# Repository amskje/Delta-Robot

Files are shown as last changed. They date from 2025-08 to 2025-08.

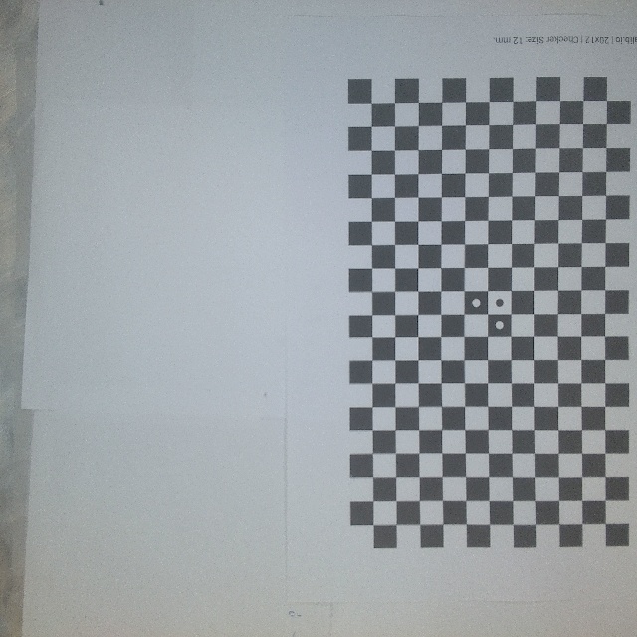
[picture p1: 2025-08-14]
Calibration/Camera_calibration/calibration_images/chessboard_frame17.jpg

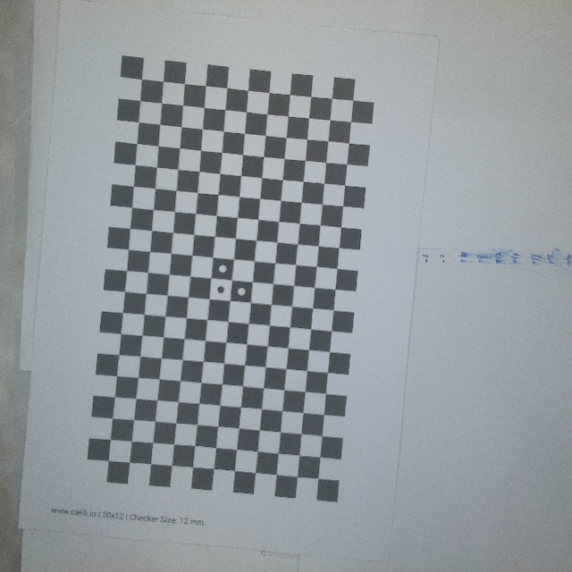
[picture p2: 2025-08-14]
Calibration/Camera_calibration/calibration_images/chessboard_frame7.jpg

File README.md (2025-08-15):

Manual for Delta-Robot @ NOV 2025
# Contents
[Abstract	1](#_toc724300322)

[Starting the system	1](#_toc895251242)

[Hardware overview	1](#_toc675706389)

[Jetson	2](#_toc1815479896)

[Raspberry Pi	2](#_toc84646506)

[Arduino	2](#_toc1544824068)

[Software nodes	2](#_toc146301729)

[Jetson	2](#_toc1467893155)

[Arduino	5](#_toc1835169055)

[Raspberry Pi	5](#_toc1901772002)

[Calibration	5](#_toc850224337)

[YOLOv8	6](#_toc1308711842)

[General	6](#_toc500146127)

## Abstract
This project is a Delta-Robot designed to sort and pick Twist candy.

The robot is supposed to follow this workflow:

1. Read user input through the HMI
1. Identify Twist matching the request
1. Pick up, transport, then deliver

The robot also has a manual mode, which lets you move it in the X, Y, and Z directions and control the pump on or off. 
## Starting the system
To start the system, just press the power button and wait. The PI boots to desktop and then starts the GUI. It takes some time to start the GUI, so be patient. When the HMI shows two options, “Manuell” and “Automatisk”, and the motor has moved to home position over the drop off location, the system is ready.

## Hardware overview
To summarize how the robot works we will walk through most of the electronics and wiring.

The delta robot has three stepper motors with a 10:1 gear ratio, each controlled by its own motor driver. These motors move the forearms and biceps, which control a suction cup end effector. The suction is generated by a vacuum pump located at the bottom of the robot. The pump is controlled by the Arduino through a relay, and the Arduino is also connected to a vacuum sensor that measures the pressure in the suction line.

A Jetson is mounted on top of the robot. It acts as the main controller, communicating with both the Arduino and the Raspberry Pi. The entire system is powered by a single power supply. Two DC-to-DC converters are used: one provides 5V for the Arduino, and the other provides 12V for the Jetson, lights, and vacuum pump. The motor drivers are powered directly from the 36V output of the main power supply.

On the top center metal plate, a Raspberry Pi camera is mounted for the robot’s vision system. At the bottom, there is a Raspberry Pi touchscreen mounted on a sliding rail, which can be pulled out to select a candy.

Most of the electronics are located at the bottom of the robot and are covered with plexiglass. To access parts like the Arduino, you’ll need an H3 Bahco screwdriver. The pickup area (the white 3D-printed plate) is screwed and glued to the metal plate. The sliding rail is also glued to the metal plate. The black plexiglass side, which has the power connection, is attached with a bracket, and the bracket is glued in place. 
### Jetson
The most powerful computer we have. Connected to the camera and runs both the YOLO model and the calculations related to kinematics. Jetson communicates with the RPi though a ethernet cable using ROS 2 and uses serial communication to communicate with the Arduino. 
### Raspberry Pi
Has a touchscreen directly connected to it. Acts as the HMI and is quite dumb.
### Arduino
Is essentially the motor controller. Tells the motor drivers how many steps to move, and in what direction. Also acts as the interface between software and analogue signals. E.g. triggering a limit switch or monitoring the air pressure in the hose.
## Software nodes
Here is link to the repository: <https://github.com/amskje/Delta-Robot>. All used code *should* be here. The repository contains all the code for the different nodes. It also includes a “Datasheets” folder with datasheets for all the robot’s components, and a folder with the 3D models that were designed and printed during the project. 
### Jetson
General information

Currently it is running Linux with Ubuntu 20.04 OS. Here is a summary of some information which could be helpful:

IP address: 192.168.1.20/24

ROS version: Foxy (i.e. 2)

Username: jetson@yahboom

Password: yahboom

(More information can be found in the config file).

There is also some trickery with switching between using its ethernet port for ROS or regular internet. In order to prep for internet just type the following in a terminal of your choice: “nmcli connection up internet-eth”. If you need ROS, this is the command: “nmcli connection up ros-direct”.

The repository is located at ~/Documents/code/Delta-Robot/. 

Boot:

The main.py program runs on boot via the /etc/systemd/system/ros2\_boot.service file and the /Documents/code/Delta-Robot/Jetson/startup\_launcher.sh file. The starup\_launcher script prepares the environment and runs the main.py. And the ros2\_boot.service tells how and when to automatically launch the main.py. 

Remember to check or set the ros-direct network connection profile when setting the Jetson to run the main.py on boot, to make sure the communication over ros is working. To activate the ros-direct connection to be automatically set, run: “nmcli connection modify ros-direct connection.autoconnect yes”, and to check if the connection is set automatic: “nmcli connection show ros-direct". 

To start the automatic boot, run this in the terminal:

`        	`sudo systemctl daemon-reexec

`        	`sudo systemctl daemon-reload

`        	`sudo systemctl enable ros2\_boot.service

sudo systemctl start ros2\_boot.service

To see the status of the program:

sudo systemctl status ros2\_boot.service

To stop the automatic booting program:

sudo systemctl stop ros2\_boot.service

To restart the program:

sudo systemctl restart ros2\_boot.service

To disabling the automatic boot of the program:

sudo systemctl disable ros2\_boot.service

If the automatic boot is enabled and you connect the Jetson to display, mouse and keyboard, the program will still run in the background. If the program is stopped, you can run the restart line to start it again, if the program is disabled you can run the four start automatic boot lines to make it run on boot again. To see the live output from the program while its running in the background you can run this:

journalctl -u ros2\_boot.service -f

To only see a set number of the last output lines run:

journalctl -u ros2\_boot.service -n 30 --no-pager

NB: need to comment out cv2.imshow in the code when running the program on boot

Code:

The main.py script controls the main program and uses different functions from files inside the modules folder. The modules folder also include the AI model weightsV3.pt, which is used to detect Twist. 

The module files are:

- vision.py
- control.py
- kinematics.py
- comms.py
- weightsV3.pt

The vision.py file is responsible for running inference on the video stream. It contains a function called start\_inference\_thread, which starts a background thread that continuously analyzes the video frames while the program is running. The goal is to detect different Twist types. The detection happens in a function called detect\_target, which returns a list of detected twists. Each item in the list is a tuple containing the name of the twist, its position in millimeters (x\_mm and y\_mm), and the confidence of the detection. For some Twist types, the function also fine-tunes the center position to make sure it’s as accurate as possible.

The control.py file handles the delivery part of the robot system. It takes care of moving the robot to pick up the Twist from a given location and then move it to the drop-off point. This file sends the proper commands to the Arduino to make that happen. It also has logic to deal with situations where a movement needs to be stopped halfway, like if an abort is triggered. In addition, it includes helper functions such as go\_to\_pos, which moves the robot to a given position, and retreat\_home, which brings it back to its starting or resting position.

The kinematics.py file does all the calculations needed to figure out how the robot should move. It takes cartesian positions (like where the Twist is and where it should go) and turns them into motor step values that the Arduino can use to move the robot arms correctly.

The comms.py file sets up and manages communication between the Jetson, Raspberry Pi and the Arduino. The Jetson uses ROS to talk to the Raspberry Pi and serial communication to talk to the Arduino. This file includes functions to send and receive messages, and it also has a function called wait\_for\_ack that waits for a specific response from the Arduino after sending it a command. 
### Arduino
The repository is located at home/delta/Desktop/Delta-Robot/Arduino.

The Arduino side consist of one file: Arduino\_main.ino. This script executes the instructions sent from the Jetson.

### Raspberry Pi
The repository is located at home/delta/Desktop/Delta-Robot.

IP addres: 192.168.1.10/24

The GUI is run in a docker to be able to use ROS. The docker is named: delta-robot-app and the container is named delta\_gui. When the system starts and the Pi boots to Desktop, the executable /home/delta/.config/autostart/HMI.desktop (HMI\_Docker) is run automatically. This script starts /home/delta/start-delta-gui.sh. This script starts the same container every time, and the main file: /home/delta/Desktop/Delta-Robot/RaspberryPi/GUIMultiplePages.py

To pull new code, do the following inside the home/delta/Desktop/Delta-Robot folder:

- Docker stop delta\_gui
- Docker rm delta\_gui
- Git pull
- Cd RaspberryPi
- Docker build –t delta-robot-app .
- Reboot

If you want to connect the RPi to Wi-Fi you need to pull out the ethernet cable to get an internet connection. 

NB: There is a known bug with the manual screen that we haven’t had time to solve. When the system first boots, the manual screen doesn’t work properly. However, if you exit to the start screen and then return to the manual screen, it works as expected. We suspect this is due to a communication issue, it seems that the “MANUAL” message from the Raspberry Pi to the Jetson is not being received correctly at the first time, so the Jetson’s main.py does not switch to the “manual” state.
### Calibration
The robot is calibrated using three methods:

1: The camera is a bit non-linear along the edges. This is accounted for by “undistorting” the picture. The undistorting function uses the file camer\_calibration.npz. This is made by taking some pictures of a chessboard in different locations around the workingarea. To produce a new calibration, the file /Delta-Robot/Calibration/Camera\_calibration/Calibrate\_camera.py can be used. When running this script, you have to define the size of the chess squares. Capture\_image.py can be used to take the pictures. 

2: When the camera returns the x and y positions of the target, these values needs to be mapped to the real world coordination system. This is done by calculating a Homography matrix. The current matrix is stored in the file: homography\_camera.npy. To recalculate this matrix, the script /Delta-Robot/Calibration/Camera\_calibration/Compute\_homography.py can be used. This requires a picture of a chessboard where the center is located exactly at the origin of the “world” coordinate system, as well as the axes aligned.

3: Different parts of the robot might be a little “off”, so a Homography matrix is calculated to map the robots coordinates to the “world” coordinates. The matrix is stored in the file homography\_ROBOT\_WORLD.json. A new matrix can be calculated by using the script /Delta-Robot/Calibration/robot\_world\_calibration.py. This requires that you run the robot to different coordinates and measures the actual “world” position of that order. You can use the script /Delta-Robot/Jetson/manualControlWithVideoInference.py to move the robot to desired locations. 

When calibrating it is important that the reference coordinate system in step 2 and 3 are exactly the same.

The coordinate system of the robot has its x axis pointing away from the HMI screen, the y axis pointing to the right and the z axis pointing up towards the roof.

## YOLOv8
In case there is need for training a new model, there is a bit over a thousand images that are stored in the private cloud belonging to Amund. These images also have corresponding .txt files with bounding boxes for training and validation of YOLO models. Note that the .txt files are in YOLO format, but it is probably easy to convert to some other format.

We recommend using *LabelImg* for manual labeling.

The current model is referred to as “weightsV3.pt” on github. You can find it at /Delta-Robot/Jetson/modules/weightsV3.pt. It is based upon the pre-trained nano model from Ultralytics. It ran 40 epochs on the dataset with some various augmentations.

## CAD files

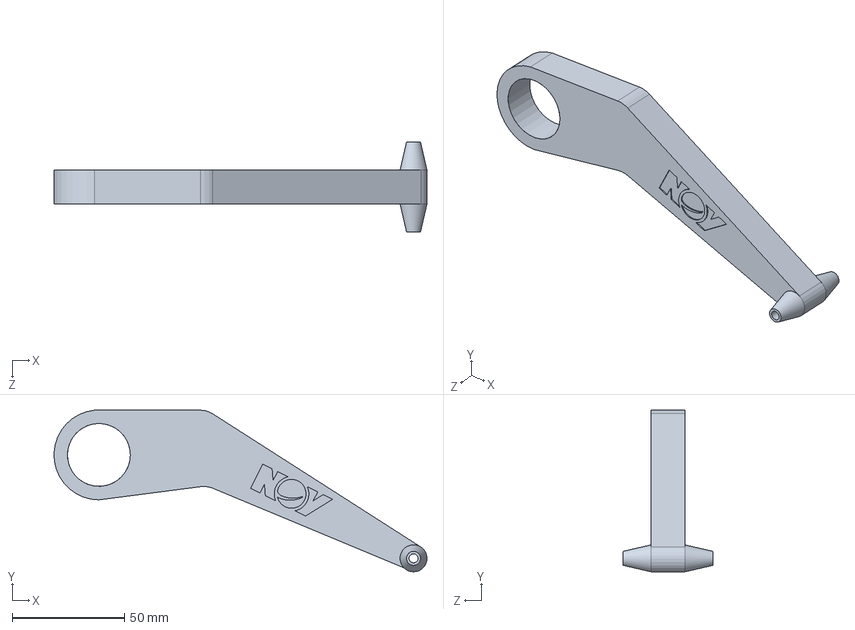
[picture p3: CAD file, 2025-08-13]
3D models/Heimelaga deler (.stl)/Bicep/BicepV3.SLDPRT
166.0 x 71.9 x 40.0 mm

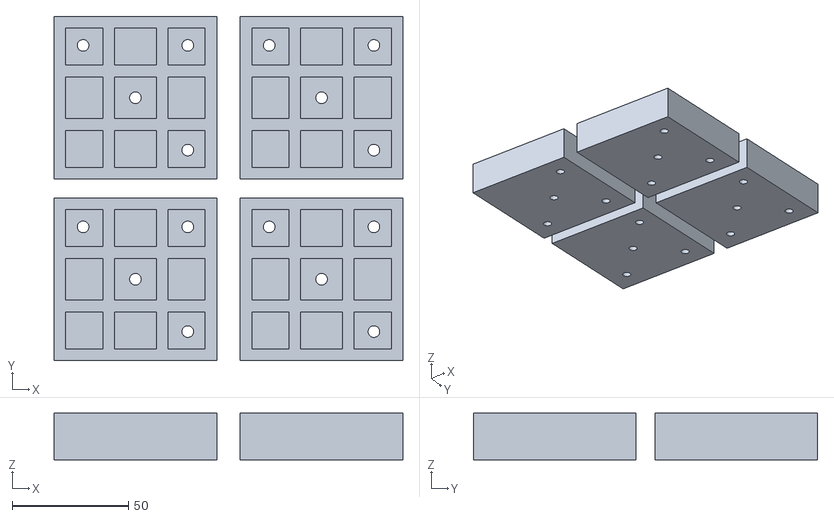
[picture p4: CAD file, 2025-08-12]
3D models/Heimelaga deler (.stl)/Bordbein/BordbeinV1 4stk.stl
150.0 x 148.0 x 20.0

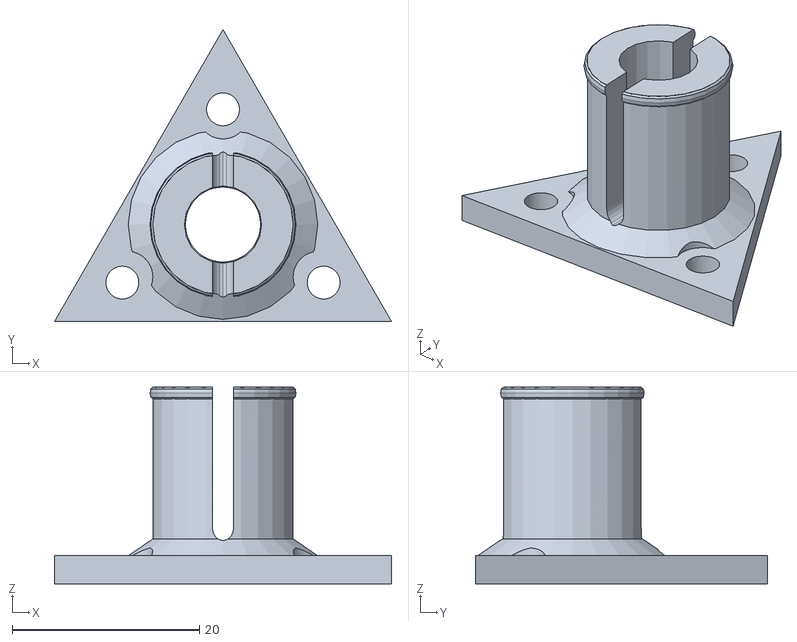
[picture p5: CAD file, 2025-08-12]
3D models/Heimelaga deler (.stl)/Endeffektor/Endeffektor V1.stl
36.0 x 31.2 x 21.0

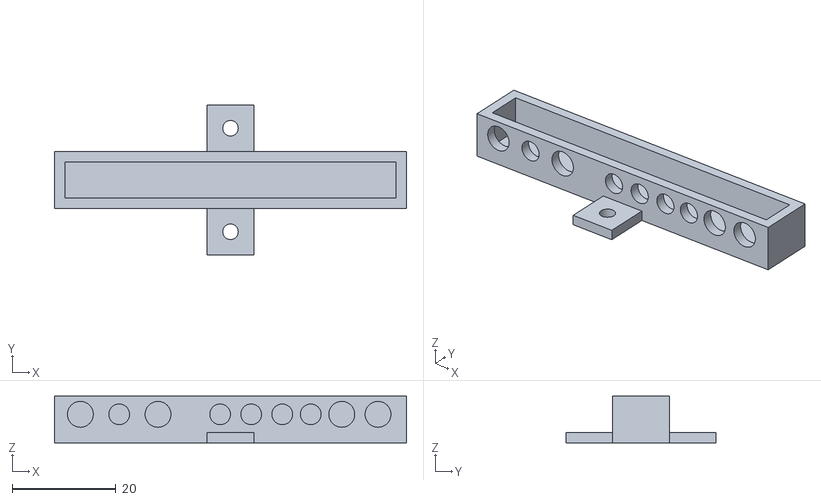
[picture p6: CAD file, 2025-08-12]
3D models/Heimelaga deler (.stl)/GND Rail/GND RailV1.stl
68.0 x 29.0 x 9.00

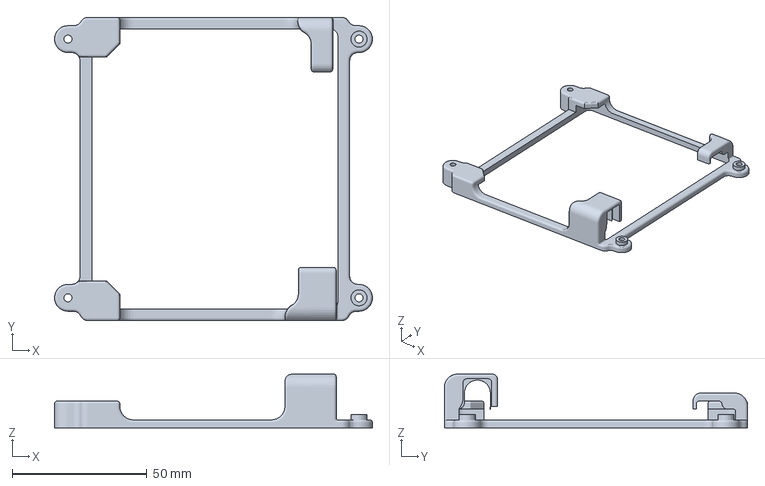
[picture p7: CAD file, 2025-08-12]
3D models/Heimelaga deler (.stl)/Jetson casing/C3-JetsonXavierNX-Mount.3mf
118.0 x 112.6 x 20.0 mm

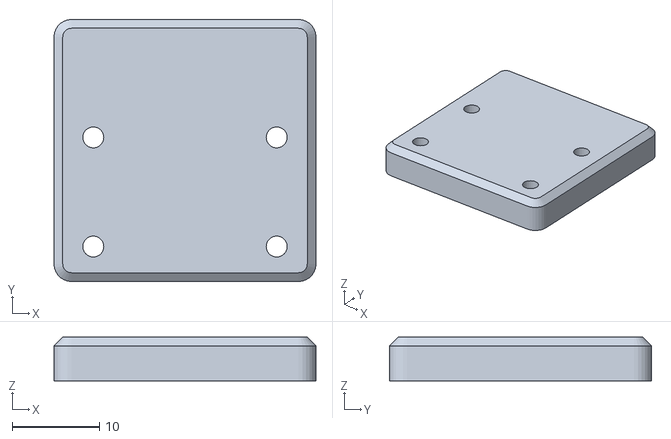
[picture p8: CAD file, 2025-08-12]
3D models/Heimelaga deler (.stl)/Kamera casing/Kamera casing del 1 V1.STL
30.0 x 30.0 x 5.00

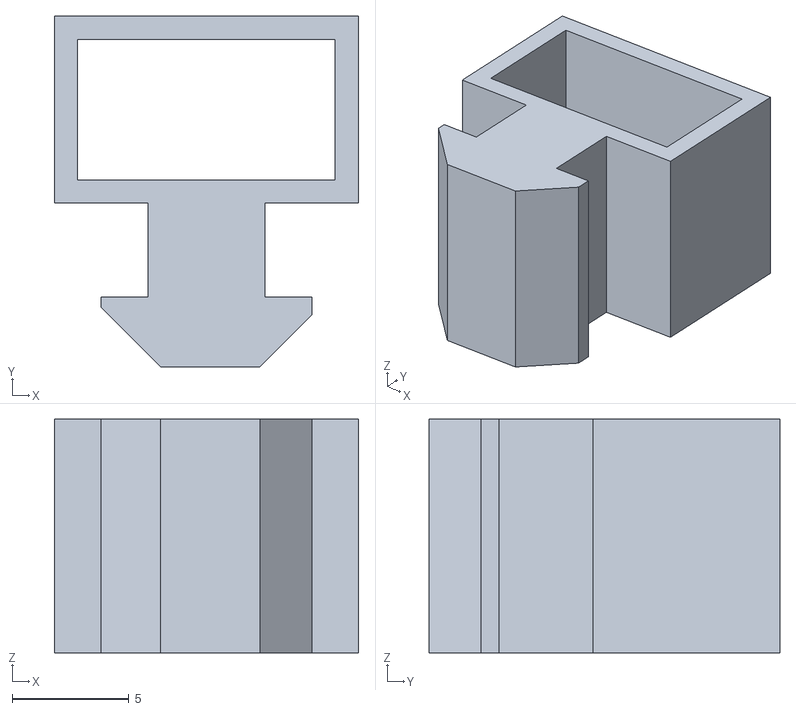
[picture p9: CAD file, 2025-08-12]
3D models/Heimelaga deler (.stl)/LED knagg/LED knagg V3.stl
13.0 x 15.0 x 10.0

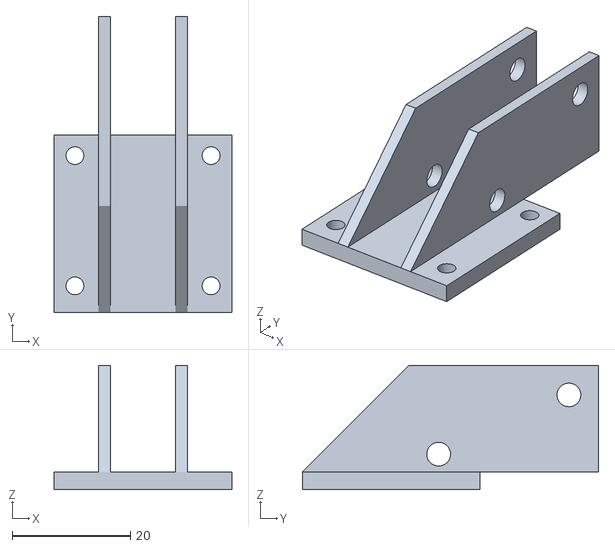
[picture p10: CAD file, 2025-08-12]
3D models/Heimelaga deler (.stl)/Limiter bracket/Limiter bracketV2.stl
30.0 x 50.0 x 21.0

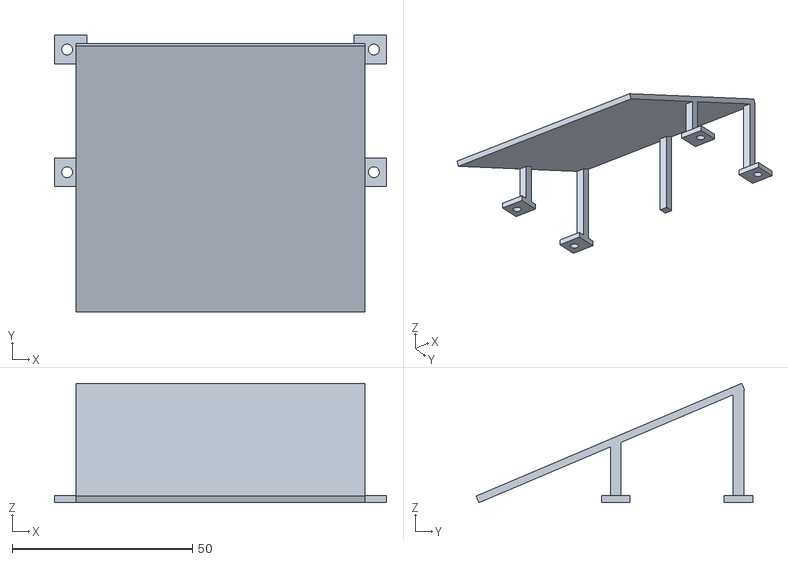
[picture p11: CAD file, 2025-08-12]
3D models/Heimelaga deler (.stl)/Sklie/Twistsklie.stl
92.0 x 76.7 x 33.1

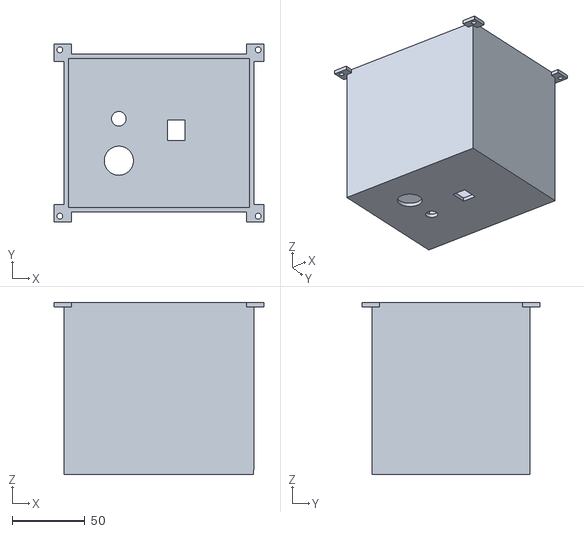
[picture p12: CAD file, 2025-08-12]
3D models/Heimelaga deler (.stl)/Støydemping/PumpecasingV1.stl
144.0 x 122.0 x 118.0

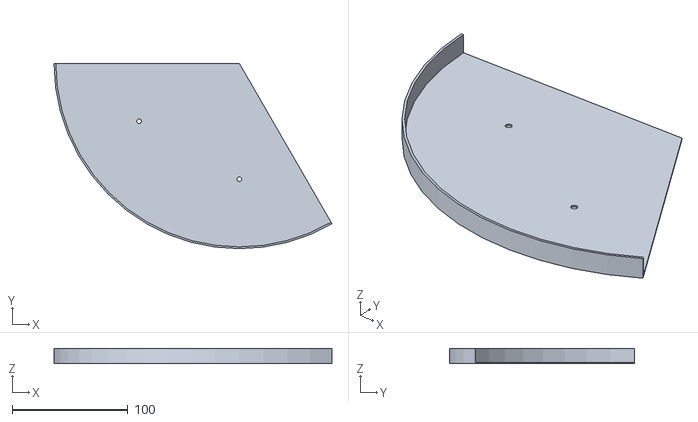
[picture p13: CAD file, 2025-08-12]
3D models/Heimelaga deler (.stl)/Underlag/UnderlagV2.stl
240.0 x 160.0 x 13.0

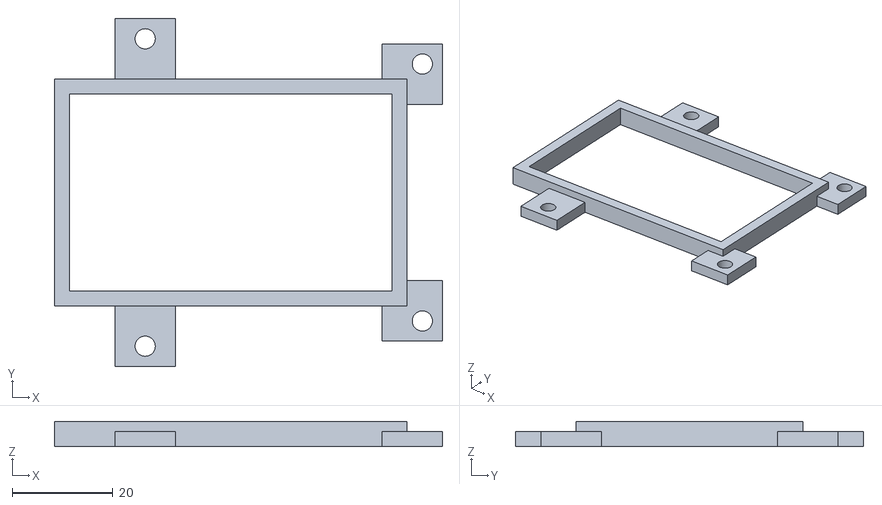
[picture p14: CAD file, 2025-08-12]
3D models/Heimelaga deler (.stl)/Vakuumpumpe casing/Vakuumpumpe casing (berre skål)V2.stl
77.0 x 69.0 x 5.00

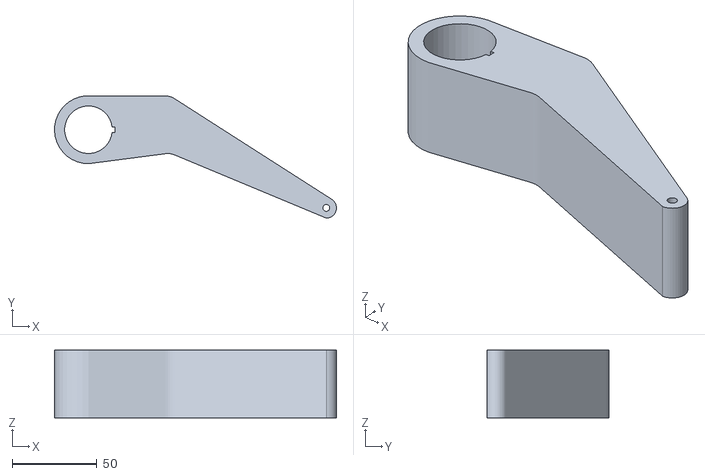
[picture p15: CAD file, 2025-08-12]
3D models/Heimelaga deler (.stl)/Bicep/Bicep40mmV2.STL
166.0 x 71.9 x 40.0

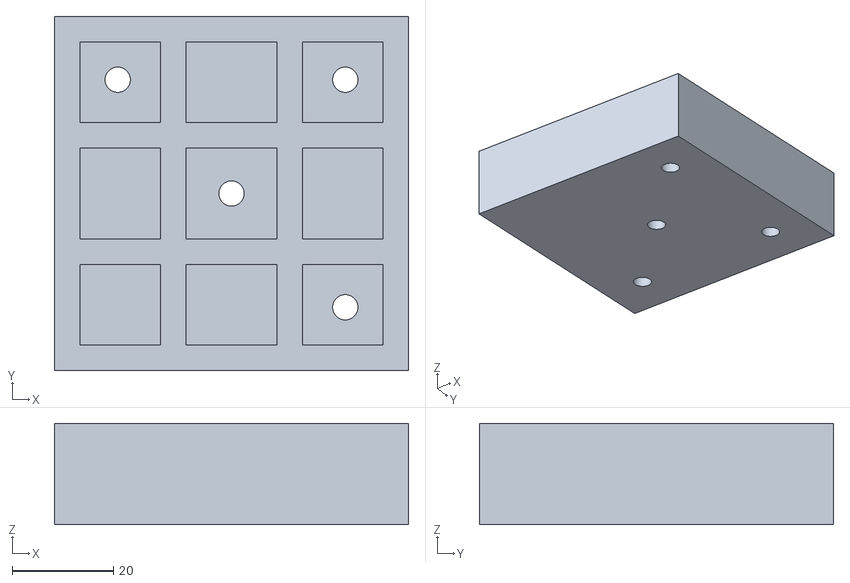
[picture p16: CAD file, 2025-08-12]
3D models/Heimelaga deler (.stl)/Bordbein/BordbeinV1 1stk.stl
70.0 x 70.0 x 20.0

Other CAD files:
3D models/Prosjekt (.3mf)/Bordbein/BordbeinV1 4stk.3mf
3D models/Heimelaga deler (.stl)/Jetson casing/Jetson casingV1.stl
3D models/Heimelaga deler (.stl)/Kamera casing/Kamera casing del 2 V1.STL
3D models/Heimelaga deler (.stl)/Powerswitch/PowerswitchV2.stl
3D models/Heimelaga deler (.stl)/Bicep/BicepOriginial.STL
3D models/Heimelaga deler (.stl)/LED knagg/LED knagg V1.stl
3D models/Heimelaga deler (.stl)/LED knagg/LED knagg V2.stl
3D models/Heimelaga deler (.stl)/Limiter bracket/Limiter bracketV1.stl
3D models/Heimelaga deler (.stl)/Powerswitch/PowerswitchV1.stl
3D models/Heimelaga deler (.stl)/Skjermcasing/Skjermcasing RPi side V1.stl
3D models/Heimelaga deler (.stl)/Skjermcasing/Skjermcasing RPi side V2.stl
3D models/Heimelaga deler (.stl)/Skjermcasing/Skjermcasing RPi side V3.stl
3D models/Heimelaga deler (.stl)/Skjermcasing/Skjermcasing skinne V1.stl
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

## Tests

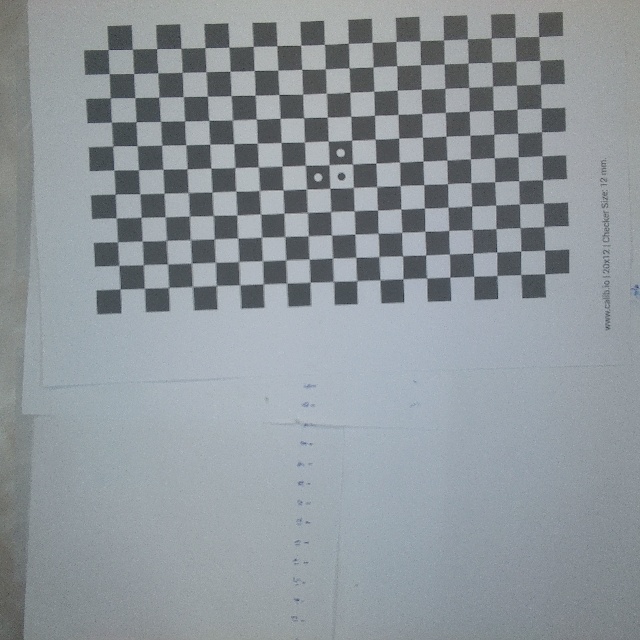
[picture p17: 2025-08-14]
Calibration/Camera_calibration/calibration_images/chessboard_frame10.jpg

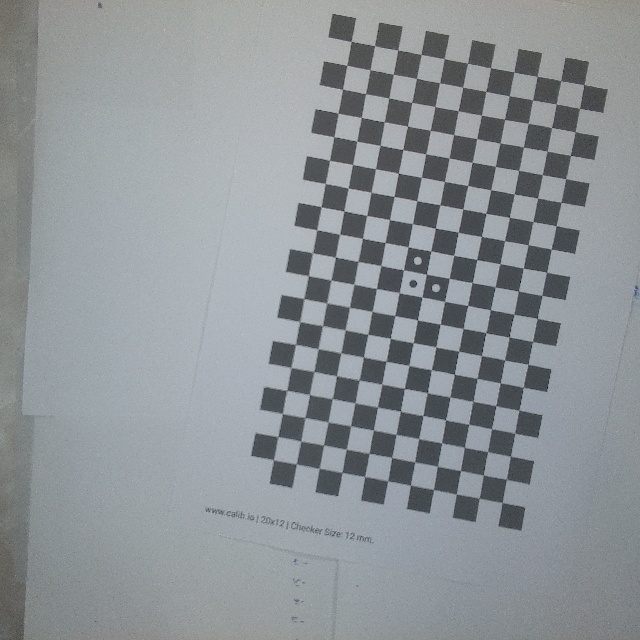
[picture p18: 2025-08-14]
Calibration/Camera_calibration/calibration_images/chessboard_frame4.jpg

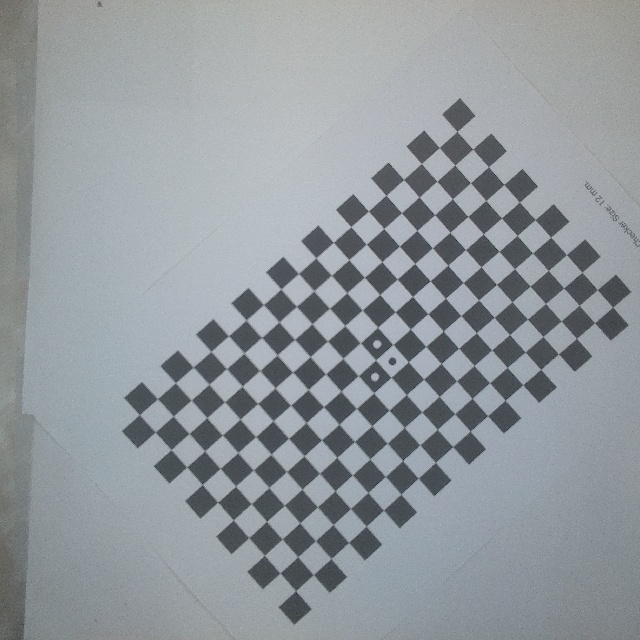
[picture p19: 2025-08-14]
Calibration/Camera_calibration/calibration_images/chessboard_frame12.jpg

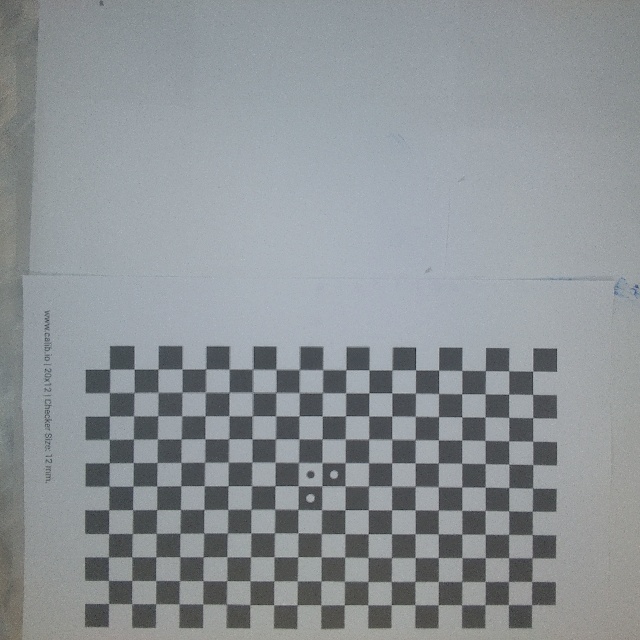
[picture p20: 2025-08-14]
Calibration/Camera_calibration/calibration_images/chessboard_frame15.jpg

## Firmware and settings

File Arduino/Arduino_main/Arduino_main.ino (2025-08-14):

#include <Arduino.h>
#include <math.h>
#include <AccelStepper.h>
#include <MultiStepper.h>



//Pin setup
#define STEP1 5
#define DIR1 10
#define LIMIT1 3

#define STEP2 7
#define DIR2 8
#define LIMIT2 2

#define STEP3 6
#define DIR3 9
#define LIMIT3 4

#define PUMP 12
#define SENSOR A0


enum State {
  IDLE,
  RUNNING,
  PICKING_UP,
  MANUAL
};

State currentState = IDLE;
bool abortRequested = false;

String inputBuffer = "";
bool newMessage = false;

//Motor set up
AccelStepper motor1(AccelStepper::DRIVER, STEP1, DIR1);
AccelStepper motor2(AccelStepper::DRIVER, STEP2, DIR2);
AccelStepper motor3(AccelStepper::DRIVER, STEP3, DIR3);

MultiStepper steppers;
                  
float pickupSpeed = 800.0; 
float minSpeed = 50.0;
float maxSpeed = 2000.0;
float maxAcceleration = 2000.0;
float setSpeed;
float manualSpeed = 1300.0;

//Move to target setup
#define MAX_WAYPOINTS 100
int positions[MAX_WAYPOINTS][3];
int lookahead_threshold = 50;
int lookahead_threshold_pick = 5;
int waypoint_count = 0;
int current_index = 0;

//Move down set up
#define MAX_PICKDOWN 10
int pickdown_positions[MAX_PICKDOWN][3];
int pickupPauseTime = 500;
int num_waypoints_down = 0; 
int current_index_down = 0;
bool receivingPickdown = false;
long extraZ = 40;

//Pressure sensor set up
const float R = 250.0;
const float Vcc = 5.0; //Arduino ref voltage
const float pickupThreshold = 0.9;  // Pressure below this means candy is picked

// Debounce set up
const unsigned long debounceDelay = 30;  // ms
unsigned long lastLimit1Change = 0;
unsigned long lastLimit2Change = 0;
unsigned long lastLimit3Change = 0;
bool stableLimit1State = HIGH;
bool stableLimit2State = HIGH;
bool stableLimit3State = HIGH;

//Drop off set up
bool dropoffPlanned = false;
bool droppoffPlannedSpeed = false;

bool pickupComplete = false;

long stepper_positions[3];  // target steps for each motor

void reset_variables() {
  waypoint_count = 0;
  current_index = 0;
  num_waypoints_down = 0;
  current_index_down = 0;
  dropoffPlanned = false;
  receivingPickdown = false;
  droppoffPlannedSpeed = false;

  pickupComplete = false;

  for (int i = 0; i < MAX_WAYPOINTS; i++) {
    positions[i][0] = 0;
    positions[i][1] = 0;
    positions[i][2] = 0;

    pickdown_positions[i][0] = 0;
    pickdown_positions[i][1] = 0;
    pickdown_positions[i][2] = 0;
  }
}


bool checkSensor() {
  const int numSamples = 3;  // Reduced from 10
  float totalPressure = 0.0;

  for (int i = 0; i < numSamples; i++) {
    int rawADC = analogRead(SENSOR);
    float voltage = rawADC * Vcc / 1023.0;
    float current_mA = voltage / R * 1000.0;
    float pressure_bar = (current_mA - 4.0) * (4.0 / 16.0);
    totalPressure += pressure_bar;
  }

  

  float avgPressure = totalPressure / numSamples;
  return avgPressure < pickupThreshold;
}


bool debounceRead(int pin, unsigned long &lastChangeTime, bool &lastStableState) {
  bool reading = digitalRead(pin);
  if (reading != lastStableState) {
    lastChangeTime = millis();  // reset debounce timer
    lastStableState = reading;
  }
  return (lastStableState == LOW && (millis() - lastChangeTime >= debounceDelay));
}


void checkLimitSwitches() {
  bool limit1Triggered = debounceRead(LIMIT1, lastLimit1Change, stableLimit1State);
  bool limit2Triggered = debounceRead(LIMIT2, lastLimit2Change, stableLimit2State);
  bool limit3Triggered = debounceRead(LIMIT3, lastLimit3Change, stableLimit3State);

  if (limit1Triggered || limit2Triggered || limit3Triggered) {
    stopAllMotors();
    reset_variables();
    digitalWrite(PUMP, LOW);
    currentState = IDLE;    
    abortRequested = false;
    homeAllMotors();
    Serial.println("LIMIT");
  }
}

void homeAllMotors() {
  stopAllMotors();

  motor1.setMaxSpeed(maxSpeed);
  motor2.setMaxSpeed(maxSpeed);
  motor3.setMaxSpeed(maxSpeed);

  bool limit1Hit = false;
  bool limit2Hit = false;
  bool limit3Hit = false;

  while (!limit1Hit || !limit2Hit || !limit3Hit) {
    // --- Motor 1 ---
    if (!limit1Hit || digitalRead(LIMIT1) == HIGH) {
      limit1Hit = false;  // released = not homed

      if (digitalRead(LIMIT1) == LOW) {
        motor1.stop();
        limit1Hit = true;  // re-homed
      } else {
        motor1.move(-10000);  // keep moving toward switch
        motor1.run();
      }
    }

    // --- Motor 2 ---
    if (!limit2Hit || digitalRead(LIMIT2) == HIGH) {
      limit2Hit = false;

      if (digitalRead(LIMIT2) == LOW) {
        motor2.stop();
        limit2Hit = true;
      } else {
        motor2.move(-10000);
        motor2.run();
      }
    }

    // --- Motor 3 ---
    if (!limit3Hit || digitalRead(LIMIT3) == HIGH) {
      limit3Hit = false;

      if (digitalRead(LIMIT3) == LOW) {
        motor3.stop();
        limit3Hit = true;
      } else {
        motor3.move(-10000);
        motor3.run();
      }
    }
  }

  // Set all home positions
  motor1.setCurrentPosition(0);
  motor2.setCurrentPosition(0);
  motor3.setCurrentPosition(0);

  // Back off from the switch
  motor1.moveTo(100);
  motor2.moveTo(100);
  motor3.moveTo(100);

  while (motor1.distanceToGo() != 0 || motor2.distanceToGo() != 0 || motor3.distanceToGo() != 0) {
    motor1.run();
    motor2.run();
    motor3.run();
  }
}


bool motorsRunning() {
  return motor1.distanceToGo() != 0 || motor2.distanceToGo() != 0 || motor3.distanceToGo() != 0;
}


void moveToPosition(int idx, int positionArray[][3], float speed) {
  motor1.setMaxSpeed(speed);
  motor2.setMaxSpeed(speed);
  motor3.setMaxSpeed(speed);

  stepper_positions[0] = positionArray[idx][0];
  stepper_positions[1] = positionArray[idx][1];
  stepper_positions[2] = positionArray[idx][2];

  steppers.moveTo(stepper_positions);

}

void stopAllMotors() {
  motor1.stop();
  motor2.stop();
  motor3.stop();
}

void readSerialMessage() {
  while (Serial.available()) {
    char c = Serial.read();
    if (c == '\n') {
      newMessage = true;
      break;
    } else {
      inputBuffer += c;
    }
  }

  if (newMessage) {
    inputBuffer.trim();

    if (inputBuffer == "POSITION") {
      Serial.println("READY");
    }
    else if (inputBuffer == "MANUAL") {
      currentState = MANUAL;
    }
    else if (inputBuffer == "AUTOMATIC") {
      stopAllMotors();
      currentState = IDLE;
      reset_variables();
      digitalWrite(PUMP, LOW);
      //homeAllMotors();
      Serial.println("EXIT_MANUAL");
      
    }
    else if (inputBuffer == "DOWN") {
      receivingPickdown = true;
      pickupComplete = false;
      Serial.println("READY");
    }
    else if (inputBuffer == "DROPP") {
      dropoffPlanned = true;
      droppoffPlannedSpeed = true;
    }
    else if (inputBuffer.startsWith("ANGLES")) {
      int a1, a2, a3;
      if (sscanf(inputBuffer.c_str(), "ANGLES %d,%d,%d", &a1, &a2, &a3) == 3) {
        if (currentState == MANUAL) {
          // Immediately move to this new manual position
          motor1.setMaxSpeed(manualSpeed);
          motor2.setMaxSpeed(manualSpeed);
          motor3.setMaxSpeed(manualSpeed);
          
          stepper_positions[0] = a1;
          stepper_positions[1] = a2;
          stepper_positions[2] = a3;
          steppers.moveTo(stepper_positions);
        }
        else if (receivingPickdown) {
          if (num_waypoints_down < MAX_PICKDOWN) {
            pickdown_positions[num_waypoints_down][0] = a1;
            pickdown_positions[num_waypoints_down][1] = a2;
            pickdown_positions[num_waypoints_down][2] = a3;
            num_waypoints_down++;
          }
        } else {
          if (waypoint_count < MAX_WAYPOINTS) {
            positions[waypoint_count][0] = a1;
            positions[waypoint_count][1] = a2;
            positions[waypoint_count][2] = a3;
            waypoint_count++;
          }
        }
      }
    }
    else if (inputBuffer == "PUMP_ON") {
      digitalWrite(PUMP, HIGH);
    }
    else if (inputBuffer == "PUMP_OFF") {
      digitalWrite(PUMP, LOW);
    }
    else if (inputBuffer == "GO" && currentState == IDLE) {
      if (waypoint_count > 0) {

        moveToPosition(current_index++, positions, maxSpeed);  // Start first move immediately
        currentState = RUNNING;
      } 
    }
    else if (inputBuffer == "ABORT") {
      abortRequested = true;
    }

    inputBuffer = "";
    newMessage = false;
  }
}


void setup() {

  Serial.begin(57600);

  pinMode(LIMIT1, INPUT_PULLUP);
  pinMode(LIMIT2, INPUT_PULLUP);
  pinMode(LIMIT3, INPUT_PULLUP);
  pinMode(PUMP, OUTPUT);
  digitalWrite(PUMP, LOW); 

  pinMode(13, OUTPUT); //LED onboard
  digitalWrite(13, LOW);  // Turn LED on

  motor1.setMaxSpeed(maxSpeed);
  motor2.setMaxSpeed(maxSpeed);
  motor3.setMaxSpeed(maxSpeed);

  motor1.setAcceleration(maxAcceleration);
  motor2.setAcceleration(maxAcceleration);
  motor3.setAcceleration(maxAcceleration);

  steppers.addStepper(motor1);
  steppers.addStepper(motor2);
  steppers.addStepper(motor3);

  homeAllMotors();

  homeAllMotors();

  Serial.println("Finished setup"); // signal Jetson
}

void loop() {
  // Read Serial
  readSerialMessage();

  if (abortRequested) {
    stopAllMotors();
    reset_variables();
    digitalWrite(PUMP, LOW);
    currentState = IDLE;    
    abortRequested = false;
    homeAllMotors();
    Serial.println("ABORTED");
  }

  switch (currentState) {
    
  case IDLE:
    break;
  

  case PICKING_UP:

    digitalWrite(PUMP, HIGH);
    if (checkSensor()){

      /*
      int squeezePosition[3] = {
        motor1.currentPosition() + extraZ,
        motor2.currentPosition() + extraZ,
        motor3.currentPosition() + extraZ  
      };

      motor1.setMaxSpeed(pickupSpeed / 2);
      motor2.setMaxSpeed(pickupSpeed / 2);
      motor3.setMaxSpeed(pickupSpeed / 2);

      stepper_positions[0] = squeezePosition[0];
      stepper_positions[1] = squeezePosition[1];
      stepper_positions[2] = squeezePosition[2];

      steppers.moveTo(stepper_positions);

      // Wait for squeeze to complete
      while (motorsRunning()) {
        steppers.run();
      }
      */
      
      stopAllMotors();

      delay(pickupPauseTime);

      current_index_down = num_waypoints_down + 1;

      if (waypoint_count > 0) {
        moveToPosition(waypoint_count - 1, positions, maxSpeed/3); 
      }
      pickupComplete = true;
      currentState = RUNNING;
      break;
    }
    
    if (current_index_down < num_waypoints_down) {
      if (motor1.distanceToGo() < lookahead_threshold_pick &&
          motor2.distanceToGo() < lookahead_threshold_pick &&
          motor3.distanceToGo() < lookahead_threshold_pick) {
          
          moveToPosition(current_index_down++, pickdown_positions, max(pickupSpeed - current_index_down*100, minSpeed));
      }
    } else if (current_index_down == num_waypoints_down) {
      if (waypoint_count > 0) {
        moveToPosition(waypoint_count - 1, positions, maxSpeed); 
      }

      Serial.println("NOT_PICKED_UP");
      digitalWrite(PUMP, LOW);
      reset_variables();
      current_index_down++;  // prevents repeating this block
      currentState = RUNNING;
    }
    break;


case RUNNING:

  // Check if the target is dropped
  if (dropoffPlanned && !checkSensor()) {
    Serial.println("DROPPED");
    reset_variables();
    digitalWrite(PUMP, LOW);
    currentState = IDLE;
  }

  // ───── LOOKAHEAD for all but the last waypoint ─────
  if (current_index < waypoint_count &&
      motor1.distanceToGo() < lookahead_threshold &&
      motor2.distanceToGo() < lookahead_threshold &&
      motor3.distanceToGo() < lookahead_threshold) {

    if (droppoffPlannedSpeed) {
      //setSpeed = min(200 + current_index * 300, maxSpeed);
      setSpeed = 800;
    } else {
      setSpeed = maxSpeed;
    }

    moveToPosition(current_index++, positions, setSpeed);
  }

  // ───── All Waypoints Done ─────
  else if (current_index == waypoint_count &&
           motor1.distanceToGo() == 0 &&
           motor2.distanceToGo() == 0 &&
           motor3.distanceToGo() == 0) {

    if (!pickupComplete && current_index_down < num_waypoints_down) {
      currentState = PICKING_UP;
      delay(25);
      motor1.setMaxSpeed(pickupSpeed);
      motor2.setMaxSpeed(pickupSpeed);
      motor3.setMaxSpeed(pickupSpeed);
    }
    else {
      if (dropoffPlanned) {
        digitalWrite(PUMP, LOW);
        dropoffPlanned = false;
      }

      Serial.println("DONE");
      reset_variables();
      currentState = IDLE;
    }
  }

  break;

  case MANUAL:
  if (motorsRunning()) {
    checkLimitSwitches();
  }
  steppers.run();  // Keep executing current manual move
  break;


  // ───── UNKNOWN STATE ─────
  default:
    Serial.println("Unknown state!");
    currentState = IDLE;
    reset_variables();
    break;
  }

  if (motorsRunning()) {
    checkLimitSwitches();
  }

  steppers.run();
}

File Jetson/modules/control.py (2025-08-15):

from . import comms
from . import kinematics
from typing import List, Tuple
from dataclasses import dataclass
import numpy as np
import json
import cv2

HOME_X = 3.038
HOME_Y = 0.1655
HOME_Z = -247.34


@dataclass
class ControlConfig:
    # Base parameters
    WAYPOINTS: int = 10 # Minimum 2
    WAYPOINTS_DOWN: int = 10 #Minimum 2
    DOWN_MM: int = 45 #Total mm robot can move down after hitting target pos
    DOWN_DAIM_MM: int = 50
    DOWN_NOTTI_MM: int = 37
    INITIAL_POSITION: kinematics.Position = kinematics.Position(HOME_X, HOME_Y, HOME_Z)  # Initial position after goHome()

    Z_WORKING = -300  # Z coordinate for working height

     # New fallback positions
    FALLBACK_STAGE1: Tuple[float, float, float] = (0.0, 0.0, Z_WORKING)
    FALLBACK_STAGE2: Tuple[float, float, float] = (-120.0, 80.0, Z_WORKING)

def config() -> ControlConfig:
    return ControlConfig()

class DeltaRobotController:
    def __init__(self, serial_comm: comms.SerialComm):
        self.serial = serial_comm  # Instance of SerialComm
        self.current_pos = [HOME_X, HOME_Y, HOME_Z] # Track robot position in mm
        self.Z_WORKING = ControlConfig.Z_WORKING  # Working height

        with open('homography_ROBOT_WORLD.json', 'r') as file:
            H_robot = json.load(file)
        
        self.H_robot_inv = np.linalg.inv(H_robot)
 
    def correct_target(self, x_desired, y_desired, z):
        """Transform a target point from real-world into robot coordinates"""
        pt = np.array([[[x_desired, y_desired]]], dtype=np.float32)
        corrected = cv2.perspectiveTransform(pt, self.H_robot_inv)
        
        return corrected[0][0]

    def check_abort(self, abort_flag, msg=""):
        if abort_flag and abort_flag.is_set():
            print(f"[Control] ABORT detected {msg}. Retreating...")
            return True
        return False

    def send_angles_sequence(self, angles_list, angles_down_list, down_included, abort_flag=None):
        self.serial.send_message("POSITION")
        ack = self.serial.wait_for_ack("READY")
        if ack != True:
            print(f"[Error] Arduino not ready for POSITION. Got: {ack}")
            return ack  # Can be unexpected msg or False (timeout)

        for angles in angles_list:
            if self.check_abort(abort_flag, "before pickup"):
                aborted = self.serial.wait_for_ack("ABORTED")
                if aborted is True:
                    print("Arduino did abort, ready to move")
                else:
                    print("arduino did not abort and is not ready to move")
                return "ABORTED"
            a1, a2, a3 = angles
            msg = f"ANGLES {int(a1)}, {int(a2)}, {int(a3)}"
            self.serial.send_message(msg)

        if down_included:
            self.serial.send_message("DOWN")
            ack = self.serial.wait_for_ack("READY")
            if ack != True:
                print(f"[Error] Arduino not ready for DOWN. Got: {ack}")
                return ack
            
            for angles_down in angles_down_list:
                if self.check_abort(abort_flag, "before pickup"):
                    aborted = self.serial.wait_for_ack("ABORTED")
                    if aborted is True:
                        print("Arduino did abort, ready to move")
                    else:
                        print("arduino did not abort and is not ready to move")
                    return "ABORTED"
                a1, a2, a3 = angles_down
                msg = f"ANGLES {int(a1)}, {int(a2)}, {int(a3)}"
                self.serial.send_message(msg)

        self.serial.send_message("GO")
        ack = self.serial.wait_for_ack("DONE")
        if ack != True:
            print(f"[Error] Arduino did not complete GO. Got: {ack}")
            return ack

        return "SUCCESS"


    def twist_delivery(self, target_pos: Tuple[float, float, float], dropoff_pos: Tuple[float, float, float], twist_type: str, include_dropoff: bool = True, abort_flag=None):
        """
        Executes a full delivery sequence from current position to target, then drop-off.
        
        Args:
            target_pos (List[int]): [x, y, z] coordinates of pickup target
            dropoff_pos (List[int]): [x, y, z] coordinates of drop-off target
        """
        print(f"[Control] Planning move to pickup at {target_pos}...")

        # === Phase 1: Plan path to pickup
        pickup_angles = []
        down_angles = []

        # Map robot coordinates to real world
        x_corrected, y_corrected = self.correct_target(target_pos[0], target_pos[1], target_pos[2])
        
        kinematics.plan_linear_move(self.current_pos[0], self.current_pos[1], self.current_pos[2],
                                    x_corrected, y_corrected, target_pos[2], pickup_angles, waypoints=config().WAYPOINTS)


        #Plan the moving down waypoints
        if (twist_type == 'Daim'):   
            kinematics.plan_linear_move(x_corrected, y_corrected, target_pos[2],
                            x_corrected, y_corrected, target_pos[2]-config().DOWN_DAIM_MM, down_angles, waypoints=config().WAYPOINTS_DOWN)
        elif (twist_type == 'Notti'):
            kinematics.plan_linear_move(x_corrected, y_corrected, target_pos[2],
                            x_corrected, y_corrected, target_pos[2]-config().DOWN_NOTTI_MM, down_angles, waypoints=config().WAYPOINTS_DOWN)
        else:
            kinematics.plan_linear_move(x_corrected, y_corrected, target_pos[2],
                            x_corrected, y_corrected, target_pos[2]-config().DOWN_MM, down_angles, waypoints=config().WAYPOINTS_DOWN)

        
        pickup_result = self.send_angles_sequence(pickup_angles, down_angles, down_included=True, abort_flag=abort_flag)


        if pickup_result != "SUCCESS":
            if pickup_result in ["NOT_PICKED_UP", "DROPPED", "ABORTED", "LIMIT"]:
                print(f"[Control] Twist delivery not completed, message recived {pickup_result}. Moving to fallback position.")
                #self.retreat_home(abort_flag=abort_flag)
                return False, pickup_result
            else:
                print(f"[Control] Error during pickup: {pickup_result}")
                return False, pickup_result
        else: 
            # Update robot position
            self.current_pos = [x_corrected, y_corrected, target_pos[2]] 


    
        # === Phase 2: Plan path to drop-off
        
        print(f"[Control] Planning move to drop-off at {dropoff_pos}...")

        # Adjust dropoff pos with H
        x_dropoff_corrected, y_dropoff_corrected = self.correct_target(dropoff_pos[0], dropoff_pos[1], target_pos[2])
        

        if include_dropoff:
            dropoff_angles = []
            kinematics.plan_linear_move(
                *target_pos,
                x_dropoff_corrected, y_dropoff_corrected, dropoff_pos[2],
                dropoff_angles,
                waypoints=config().WAYPOINTS
            )
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

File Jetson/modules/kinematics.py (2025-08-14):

import math
from typing import List, Tuple
from dataclasses import dataclass

@dataclass
class KinematicsConfig:
    # Base geometry [mm]
    r_base: float = 2*math.sqrt(3)*70.0
    r_end: float = 2*math.sqrt(3)*25.0
    l_biceps: float = 147.37
    l_forearm: float = 250.0

    # Stepper settings
    pulses_per_rev: int = 8000

    def __post_init__(self):
        self.tan30 = math.tan(math.radians(30))
        self.cos120 = math.cos(math.radians(120))
        self.sin120 = math.sin(math.radians(120))
        self.ZERO_ANGLE1 = 407 * 360 / self.pulses_per_rev
        self.ZERO_ANGLE2 = 378 * 360 / self.pulses_per_rev
        self.ZERO_ANGLE3 = 428 * 360 / self.pulses_per_rev

def config() -> KinematicsConfig:
    return KinematicsConfig()

path_points = []
path_angles = []
path_index = 0
path_running = False

class Position:
    def __init__(self, x=0.0, y=0.0, z=0.0):
        self.x = x
        self.y = y
        self.z = z

def single_arm_ik(x0, y0, z0):
    conf = config()

    y1 = -0.5 * conf.tan30 * conf.r_base
    y0 -= 0.5 * conf.tan30 * conf.r_end

    a = (x0 * x0 + y0 * y0 + z0 * z0 + conf.l_biceps * conf.l_biceps - conf.l_forearm * conf.l_forearm - y1 * y1) / (2 * z0)
    b = (y1 - y0) / z0

    d = -(a + b * y1) * (a + b * y1) + conf.l_biceps * (b * b * conf.l_biceps + conf.l_biceps)
    if d < 0:
        return -1, None

    yj = (y1 - a * b - math.sqrt(d)) / (b * b + 1)
    zj = a + b * yj
    theta = math.degrees(math.atan2(-zj, y1 - yj))
    return 0, theta

def inverse_kinematics(x0, y0, z0):
    conf = config()
    status, theta1 = single_arm_ik(x0, y0, z0)
    if status != 0:
        return -1, None, None, None

    status, theta2 = single_arm_ik(x0 * conf.cos120 + y0 * conf.sin120, y0 * conf.cos120 - x0 * conf.sin120, z0)
    if status != 0:
        return -1, None, None, None

    status, theta3 = single_arm_ik(x0 * conf.cos120 - y0 * conf.sin120, y0 * conf.cos120 + x0 * conf.sin120, z0)
    if status != 0:
        return -1, None, None, None

    if theta1 is None or theta2 is None or theta3 is None:
        return 0, theta1, theta2, theta3
    
    # Adjust angles for limit offsets
    return 0, theta1 - conf.ZERO_ANGLE1, theta2 - conf.ZERO_ANGLE2, theta3 - conf.ZERO_ANGLE3

def plan_linear_move(
    x0: float, y0: float, z0: float,
    x1: float, y1: float, z1: float,
    angles_list: List[Tuple[int, int, int]],
    waypoints: int
    ):
    """
    Generate linear path from (x0, y0, z0) to (x1, y1, z1), compute IK for each step,
    and fill the given `angles_list` with tuples of (theta1, theta2, theta3).

    Parameters:
        x0, y0, z0: Start coordinates
        x1, y1, z1: End coordinates
        angles_list: List to be filled with IK angle tuples
        waypoints: Number of linear interpolation steps
    """

    angles_list.clear()  # Ensure the list is empty before filling

    for i in range(waypoints):
        t = i / (waypoints - 1)
        x = x0 + t * (x1 - x0)
        y = y0 + t * (y1 - y0)
        z = z0 + t * (z1 - z0)
        status, theta1, theta2, theta3 = inverse_kinematics(x, y, z)

        # Skip if any angle is clearly invalid (None used as error signal)
        if theta1 == None or theta2 == None or theta3 == None:
            print(f"Skipping invalid angles at step {i}: ({theta1}, {theta2}, {theta3})")
            continue

        angles_list.append((
            round(theta1 * config().pulses_per_rev / 360),
            round(theta2 * config().pulses_per_rev / 360),
            round(theta3 * config().pulses_per_rev / 360)
        ))

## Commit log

no date lagt til at når programment avsluttes lukkes komunikasjonen og camera først
no date hvis den mottar uforutsett meling reseter den og går til idle, lagt til mapping på to z plan isteden for ett
    [control.py, vision.py]
2025-07-04 Lagt til detection scriptet som køyrer på Jetson.
2025-07-04 Laga eit script som skal køyre med Arduino, og eit som er standalone Jetson
2025-07-04 Raspberry pi filer
2025-07-04 Detection script uten videofeed til skjerm kobla til Jetson.
2025-07-04 Detection med videofeed til skjerm kobla til Jetson.
2025-07-04 kinematics opprettet
2025-07-04 Arduino_main forste utkast
2025-07-07 Test script for kommunikasjon mellom pi og jetson, funket
2025-07-07 Twix knapp sender meling til jetson
2025-07-07 Pathplanning i python til Jetson
2025-07-08 Lagd utkast til jetsons moduloppsett
2025-07-08 Fjernet dobbel kompansering for home position. Nå skjer det bare i kinematics
2025-07-09 Får kamera til å åpne. Jetson sender waypoints, men Arduino responderer ikkje.
2025-07-09 Fiksa pulses per rev, renama modul mappa til Jetson, lagt til ein del debuggingsprint som kan slettes seinere
2025-07-10 Slettet gamel Arduino_main.ino fil
2025-07-10 Satte ny max for waypoints, og la til definisjon for klassen Position
2025-07-10 Oppdatert Arduino fil, og sletta ei mappe
2025-07-10 Venter på at Arduino fullfører setup() før den fortsetter
2025-07-10 Lagt til print statements for debugging
2025-07-11 Lagt til offset for senter mellom kamera og kinematikk
2025-07-11 Deleted old main arduino file
2025-07-14 Fix av imports i pakker
    [control.py, kinematics.py, vision.py]
2025-07-14 Bytta ut global running variabel med ein event i threading
2025-07-14 Gjort topic lik på RPi og Jetson
2025-07-14 Flytta main.py til Jetsonmappa
2025-07-14 Kommunikasjon mellom jetson og raspberry pi funker
2025-07-15 Sletta arduino mappa
2025-07-16 Prøvd å implementere at roboten skal skru på pumpa og bevege seg litt og litt ned hvis den ikke fikk hentet den
2025-07-16 Fikset arduino konden, slik at den ikke beveger seg oppover etter den har nådd target og bevegd seg nedover
2025-07-21 kinematics forbedret, og 8000 steps
2025-07-21 Initial_Position gjort til kinematics.Position
2025-07-21 fikset trekke fra limit angle i nye kinematics
2025-07-21 test av nye kinematics og working area calculator
2025-07-28 Camera calibration
2025-07-28 Endret Videocapture il riktige parametre
2025-07-30 robot world calibration
2025-07-30 Robot world calibration lagt til
2025-07-30 sjekke camera H visuelt
2025-08-06 la til to topics. en hver vei til PI
2025-08-08 Byttet popup til en frame
2025-08-08 fikset at den kjører programmet på boot,melings flow mellom rpi jetson og arduino, ikke ferdig med å motta abort og deetter flytte roboten til idle
2025-08-11 prøvd å fikse abort komunikasjon med rpi og arduino
2025-08-11 abort kommunikasjon med arduinoog rpi fungerer
2025-08-12 Lagt til data blad og 3d print
    [Bicep40mmV2.STL, BicepOriginial.STL, BordbeinV1 1stk.stl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]
2025-08-13 lagt til bicep.v3 i 3D mappa
    [Bicep40mmV2.STL, BicepOriginial.STL, BicepV3.SLDPRT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]
2025-08-13 endret navn på 3D mappa
    [Bicep40mmV2.STL, BicepOriginial.STL, BicepV3.SLDPRT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]
2025-08-13 removed some prints
2025-08-13 send MANUAL 3 times, small button fixes
2025-08-13 lagt til reset knapp som reseter jetson
